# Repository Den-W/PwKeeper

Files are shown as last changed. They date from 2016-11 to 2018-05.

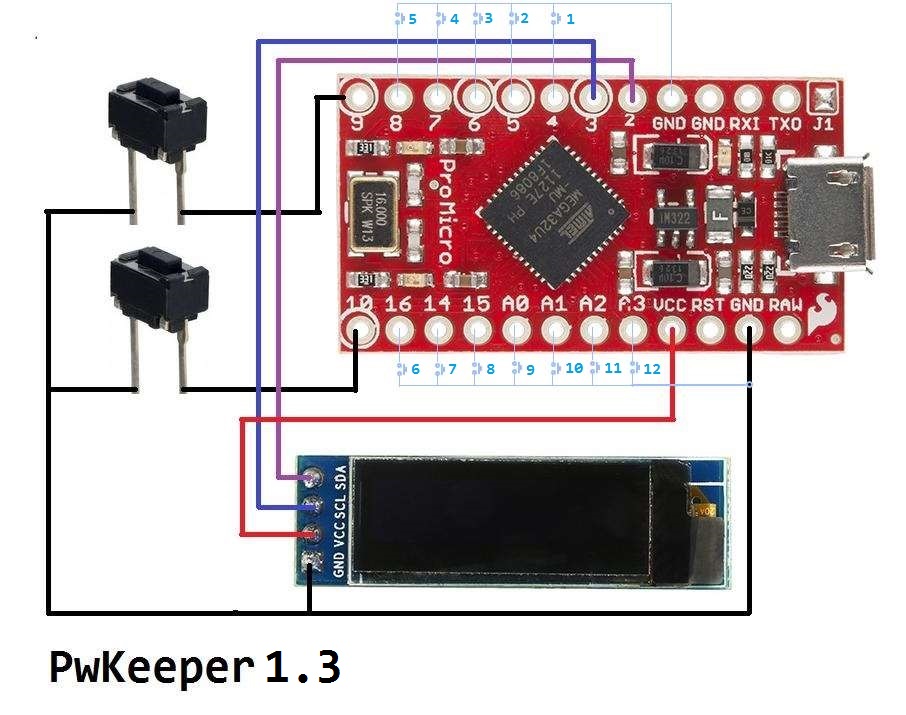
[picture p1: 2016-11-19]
PwKeeper-wiring.jpg

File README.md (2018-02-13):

*****************   PasswordKeeper v1.05   ***********************

This is a simple hand made device for storing your passwords.
Essentially, it emulates USB keyboard and should work with any device where USB keyboard may be connected.
It sends user-defined sequences of keypresses as if they were entered from keyboard.
To simplify password management in token Windows program PwKeeperPC.exe is included into the package.
Also, serial console added to device. It allows config device from *nix systems.

------------------------------------------------------------------
How to write HEX to board:

1) Download and install software from arduino.cc
2) Connect your board to PC and install all necessary drivers.
3) Open DeviceManager window. Open COM and LPT node. There you should see you board as virtual COM port.
4) On Arduino board connect RST pin to GND.
5) In COM and LPT node new COM port should appear on ~8 sec. And then it replaced by port, which you have seen already.
   If you do not see new ports to appear try to repeat step 4, but connect RST to GND 2 times with interval of 1 sec between tries.
6) Replace COM16 in command in CMD file with port, which appears temporarily.
   Check pathes to AVRDUDE.EXE and avrdude.conf in command.
   Correct it according to your system.
7) Connect RST pin to GND. Start CMD and remove RST to GND connection.
   Download to board should pass.

Essentialy, COM port that you see when board is in idle state - it is HID port. It is not the LOADER port. Board LOADER COM appears only on short period after reset.
-------------------------------------------------------------------   

Changes history:

v1.5 - 13.02.2018
        - Bugfix in login transmit procedure.

v1.4 - 24.11.2016
	- *nix-like TTY console added to PwKeeper
	- Commands description added to rtf.

v1.3 - 16.11.2016
	- Several bugfixes in PwKeeperPC.exe
	- Several bugfixes in PwKeeper.hex
 	- *.stl files added
	- Quick access buttons added to wiring diagram

v1.2 - 10.11.2016 
	- First public release

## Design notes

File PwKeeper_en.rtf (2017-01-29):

Password Keeper v 1.04.
Url: Instruction (http://www.instructables.com/id/PasswordKeeper-From-Aruino-Pro-Micro-or-Why-Keep-I/)

1. Menu structure
• Password
If main password is not set, then jump on Selection.
!!! If you forgot the main password – there is no way to restore it.
!!! You should clear all data in token – that will reset password to empty.
o Up, Down, Double Up, Double Down
Enter password data.
o Long Up => If password OK, then jump on Selection
o Long Down => Jump on Reset. – If you forgot password
• Select record
o Up, Down – Move up or down.
o Double Up, Long Up => Send data to USB.
o Double Down => Edit record
o Long Down => Device Menu
• Edit record
o Up, Down – Change current selection.
Disp – Displayed comment
Name – Login
Psw - Passwors
Del! - Delete entire record.
o Double Up, Long Up => Edit text field.
o Double Down, Long Down => Jump to Selection or Save
• Edit text field
o Up, Down – Move along the string.
o Double Up, Long Up => Edit symbol.
o Double Down, Long Down => Edit record.
• Edit symbol
o Up, Down – Change symbol.
o Double Up, Double Down => jump to Edit text field.
o Long Up – Add symbol.
o Long Down – Delete symbol.
• Device menu
o Up, Down – Change current selection.
o USB – Communicate with PwKeeperPc.
TTY – *NIX serial console
PSW – Set main password
CLR – Jump to Reset.
o Double Up, Long Up => select action.
o Double Down, Long Down => Exit.
If data were changed, jump to Save.
• Reset
o Double Up, Long Up – Clear all data in PwKeeper, including main password.
o Up, Down, Double Down, Long Down – Do not clear.
• Save
o Double Up, Long Up – Save changed data.
o Up, Down, Double Down, Long Down – Restore previous data.

2. Special symbols and macros

Key | Press | Release
KEY_LEFT_ALT | \a | \A
KEY_BACKSPACE | \b | \B
KEY_LEFT_CTRL | \c | \C
KEY_DELETE | \d | \D
KEY_ESC | \e | \E
KEY_RIGHT_SHIFT | \f | \F
KEY_RIGHT_ARROW | \g | \G
KEY_HOME | \h | \H
KEY_INSERT | \i | \I
KEY_CAPS_LOCK | \k | \K
KEY_LEFT_ARROW | \l | \L
KEY_END | \n | \N
KEY_PAGE_DOWN | \o | \O
KEY_PAGE_UP | \p | \P
KEY_RIGHT_ALT | \q | \Q
KEY_RETURN | \r | \R
KEY_LEFT_SHIFT | \s | \S
KEY_TAB | \t | \T
KEY_UP_ARROW | \u | \U
KEY_LEFT_GUI | \v | \V
KEY_DOWN_ARROW | \w | \W
KEY_RIGHT_GUI | \x | \X

Delay 300ms \z
Delay 1000ms \Z
Release all buttons \@
Sequence \[….]

For example, Ctrl-Alt-Del may be coded as \c\a\v\z or \[cavz]

System login and WORD start example:
Disp: Work-Comp V1: \[cavz
Login: V5:\[zv]word\r
Passw: Secret123\r

Site login example:
Disp: MyBank
Login: 45978726234\t
Passw: zzFFeerrr123\r

3. TTY - *NIX serial console

A serial console added in v1.04 firmware. It’s a courtesy for *nix community. This console allows editing of data inside PwKeeper by several VI-like commands. For console activation it is necessary manually select menu item “Device Menu”->”TTY”. After entering into TTY mode PwKeeper opens virtual COM port. Use any suitable terminal program for interaction with it. In TTY mode device echoes all incoming strings and shows all fields of current record.

Commands:
? - Show brief commands help.
U - Go to first record
D - Go to last record
u - Go one record up
d - Go one record down
W - Set main password. Main password sets by a combination of chars:
u – Upper button click
U – Upper button double click
d – Lower button click
D – Lower button double click
uuDDUd = 2 click up, 2 doubleclick down, 1 doubleclick up, 1 click down
!!! It is very dangerous command. You must enter password on following powerups!
A - Add new record
E - Erase current record entirely
C - Set Comment field of current record.
N - Set Name field of current record.
P - Set Password field of current record.
1-9 - Set V1 – V6 fields of current record.
Examples:
>WuuDd - Set main password: 2 single UP click, 1 double down, 1 single down.
>U - Go to first record in token
>CAOL-my - Set comment of current record to “AOL-my”
>3 - Remove field V3
>1\[cavz - Set field V1 to Ctrl-Alt-Del + delay(300)

4. Loading of HEX file and connecting with PwKeeperPc.
There is LOAD_HEX.CMD file for loading HEX into Arduino Pro Micro in the project on GITHUB (https://github.com/Den-W/PwKeeper).
1) Install Arduino IDE (http://arduino.ru/Arduino_environment) and check pathes to AVRDUDE.EXE and avrdude.conf in command below. Correct it according to your system.
!!! Important !!! If there are spaces in path on your system, do not forget frame all path with ““
2) Open DeviceManager window on COM and LPT node.
3) Plug in Arduino Pro Micro to PC USB or connect RST pin with GND 2 times with 1 sec interval.
4) In COM and LPT new COM port should apper. After ~8 it would change its number on another one, which you will see all the time, while device connected to PC.
Replace COM16 in the command with port, which you see first after reset\plug in.
Not the one you see all the time!
5) After editing CMD file repeat reset procedure or replug token to PC.
While “disappearing” COM port is still visible start LOAD_HEX.CMD.
Loading should pass. You will see 0\0 and blinking dot on the screen.

PwKeeperPc:
For connecting with PwKeeperPc you should go to DeviceMenu.
Do Lower Button Long Press. Select USB and do Double or long press on upper button.
You should see USB: 0\0 on the screen.
Then you may press Read\Write buttons on PwKeeperPC.
PwKeeperPc can see token only in this mode.

Unix\Serial console:
For connecting with token in command mode you should go to DeviceMenu.
Do Lower Button Long Press. Select TTY and do Double or long press on upper button.
You should see TTY: 0\0 on the screen.
Then start any suitable communication program on COM port.
In Arduino IDE you may use built-in console (Ctrl-Shift-M). With VI-like commands you may edit data in token.

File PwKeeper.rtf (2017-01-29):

Password Keeper v 1.04.
Описание: Ссылка1 (http://mysku.ru/blog/aliexpress/46651.html), Ссылка2 (http://radiokot.ru/circuit/digital/security/53/)

1. Структура меню устройства.

• Пароль
Если главный пароль не установлен, PwKeeper сразу переходит к Выбору
!!! Если вы забыли пароль – восстановить его нельзя, только стереть все данные в устройстве и сбросить пароль в пустой !!!
o Up, Down, Double Up, Double Down
Ввод символов пароля.
o Long Up => если пароль правильный переход к Выбору.
o Long Down => Переход на Сброс. – Если вы забыли пароль.
• Выбор записи
o Up, Down – движение по списку.
o Double Up, Long Up => Отправить пароль.
o Double Down => Редактирование записи
o Long Down => Меню настроек устройства
• Редактирование записи
o Up, Down – движение по меню.
Disp – Комментарий
Name – Login
Psw - Пароль
Del! - Удалить запись целиком.
o Double Up, Long Up => редактировать элемент.
o Double Down, Long Down => Выбор записи или Сохранение данных
• Редактировать элемент
o Up, Down – движение по строке.
o Double Up, Long Up => Редактировать символ
o Double Down, Long Down => Редактирование записи
• Редактировать символ
o Up, Down – Смена символа.
o Double Up, Double Down => сохранить символ и перейти в Редактировать Элемент
o Long Up – Добавить символ
o Long Down – Удалить символ
• Меню настроек
o Up, Down – движение по меню.
USB – режим взаимодействия с PwKeeperPc
TTY – Консоль управления
PSW –Установить главный пароль
CLR – Переход на Сброс.
o Double Up, Long Up => выбор пункта.
o Double Down, Long Down => Выxoд
Если данные были изменены – переход на сохранение
• Сброс
o Double Up, Long Up – Cтереть все данные в устройстве.
o Up, Down, Double Down, Long Down – отказаться от сброса
• Сохранение данных
o Double Up, Long Up – Записать новые данные.
o Up, Down, Double Down, Long Down – отказаться от записи

2. Спецсимволы и макросы для управления кнопками

Кнопка | Нажать | Отпустить
KEY_LEFT_ALT | \a | \A
KEY_BACKSPACE | \b | \B
KEY_LEFT_CTRL | \c | \C
KEY_DELETE | \d | \D
KEY_ESC | \e | \E
KEY_RIGHT_SHIFT | \f | \F
KEY_RIGHT_ARROW | \g | \G
KEY_HOME | \h | \H
KEY_INSERT | \i | \I
KEY_CAPS_LOCK | \k | \K
KEY_LEFT_ARROW | \l | \L
KEY_END | \n | \N
KEY_PAGE_DOWN | \o | \O
KEY_PAGE_UP | \p | \P
KEY_RIGHT_ALT | \q | \Q
KEY_RETURN | \r | \R
KEY_LEFT_SHIFT | \s | \S
KEY_TAB | \t | \T
KEY_UP_ARROW | \u | \U
KEY_LEFT_GUI | \v | \V
KEY_DOWN_ARROW | \w | \W
KEY_RIGHT_GUI | \x | \X

Задержка на 300мс \z
Задержка на 1000мс \Z
Отпустить все кнопки \@
Последовательность \[….]

Например, Ctrl-Alt-Del можно записать как \c\a\v\z или как \[cavz]

Пример настроек для входа в систему:
Имя: Комп-Работа V1: \[cavz
Login: Ivanov_PS\t V5:\[zv]word\r
Пароль: Secret123\r

Пример настроек для входа в банк:
Имя: Сбер-Дебет
Login: 45978726234\t
Пароль: zzFFeerrr123\r

3. TTY - *NIX консоль управления

В firmware v1.04 добавлена консоль управления, специально для работы с устройством из *nix ОС. Эта консоль позволяет редактировать данные в PwKeeper с помощью нескольких команд, похожих по синтаксису на VI команды.
Для запуска консоли надо выбрать кнопками пункт меню “Device Menu”->”TTY”. После старта открывается виртуальный COM порт. К нему можно подсоединиться любой подходящей программой эмуляции терминала. В режиме TTY устройство отправляет обратно все введенные строки и отображает все поля текущей записи.

Команды:
? - Краткий справочник команд.
U - Переход на первую запись
D - Переход на последнюю запись
u - Переход на одну запись вверх
d - Переход на одну запись вниз
W - Установить главный пароль. Пароль состоит из символов:
u – Однократное нажатие вверх
U – Двукратное нажатие вверх
d – Однократное нажатие вниз
D – Двукратное нажатие вниз
uuDDUd = 2 up, 2 double down, 1 double up, 1 down
!!! Это опасная команда. Этот пароль будет всегда требоваться при включении!
A - Добавить новую запись
E - Удалить текущую запись
C - Установить поле Comment.
N - Установить поле Name.
P - Установить поле Password.
1-6 - Установить поля V1 – V6.
Примеры:
>WuuDd - Установить главный пароль: 2 single up, 1 double down, 1 single down.
>U - Перейти к первой записи
>CAOL-my - Установить отображаемый коментарий в “AOL-my”
>3 - Удалить поле V3
>1\[cavz - Установить поле V1 в Ctrl-Alt-Del + задержка 300 мс

4. Загрузка и работа
Для загрузки HEX в Arduino Pro Micro в проекте на GITHUB (https://github.com/Den-W/PwKeeper) есть файл LOAD_HEX.CMD.
1) Установить Arduino IDE (http://arduino.ru/Arduino_environment) и проверить путь к AVRDUDE.EXE и avrdude.conf. Исправьте пути в CMD в соответствии с Вашей системой.
!!! Важно!!! Если путь содержит пробелы, не забудьте обрамить его кавычками “ !
2) Откройте окно DeviceManager. Откройте COM and LPT узел.
3) Подключите Arduino Pro Micro к USB или замкните RST пин на GND 2 раза с интервалом около 1 сек.
4) В устройствах COM and LPT появится новый COM порт. И через ~8 сек он поменяется на другой, который будет виден пока устройство подключено.
Замените COM16 в команде на порт, который появлялся первым, а не на тот, что виден всегда!
5) После того, как в CMD файл внесены изменения повторите процедуру сброса или подсоедините плату к компу заново. Пока виден “исчезающий” COM порт запустите LOAD_HEX.CMD.
Загрузка должна пройти. Вы увидите на экране 0\0 и мигающую точку – значит все работает.

PwKeeperPc:
Для соединения с PwKeeperPc вам нужно перейти в МенюНастроек.
Для этого при первом включении выполните долгое нажатие кнопки Вниз, выберите пункт USB и 2 раза или долго нажмите на верхнюю кнопку.
Появится надпись USB: 0\0.
После этого можно нажимать кнопки Чтение\Запись на PwKeeperPC. Программа PwKeeperPc видит токен только в этом режиме.

Unix\Serial console:
Для соединения в командном режиме вам нужно перейти в МенюНастроек.
Для этого при первом включении выполните долгое нажатие кнопки Вниз, выберите пункт TTY и 2 раза или долго нажмите на верхнюю кнопку.
Появится надпись TTY: 0\0.
Далее запустите какую-либо программу терминала. В Arduino IDE можно использовать встроенную консоль (Ctrl-Shift-M). Используя VI-подобные команды из параграфа 3 можно редактировать данные в токене.

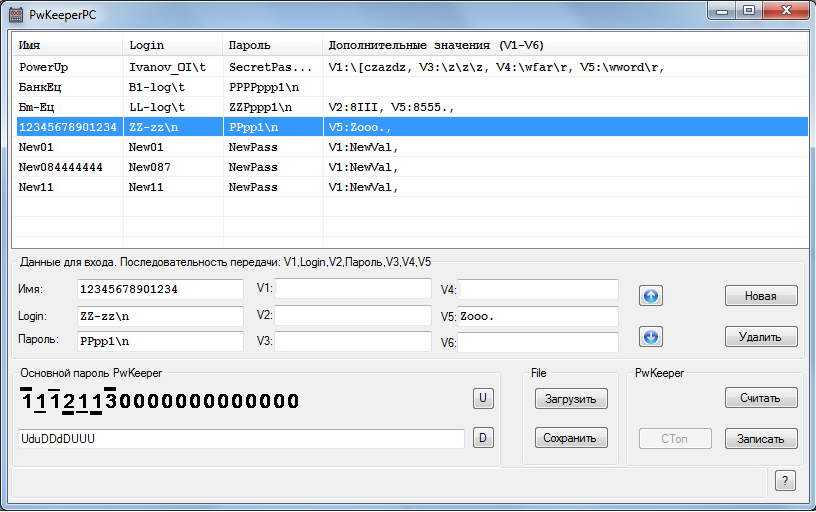
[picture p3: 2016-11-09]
PwKeeperPC.png

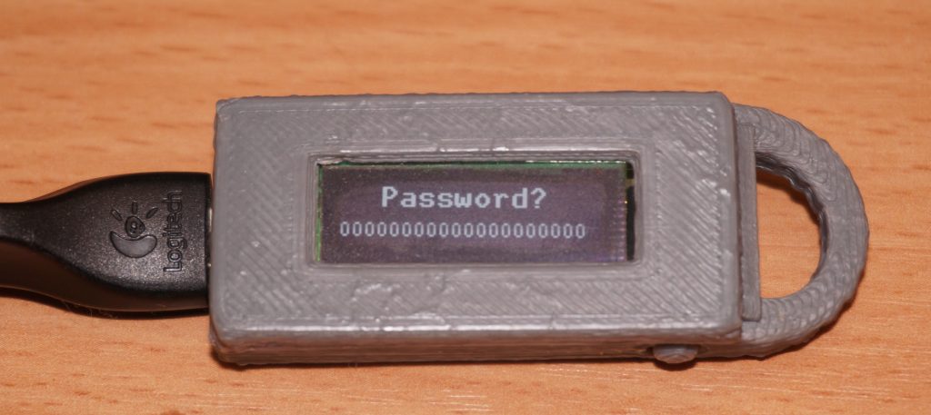
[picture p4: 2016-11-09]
PwKeeper-work.jpg

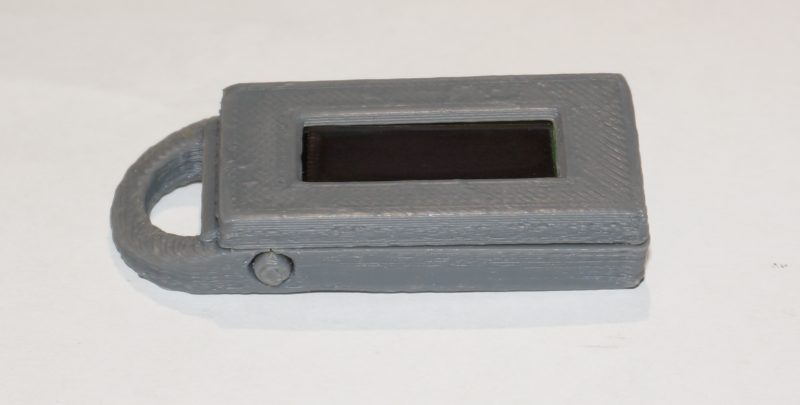
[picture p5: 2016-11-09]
PwKeeper-rdy.jpg

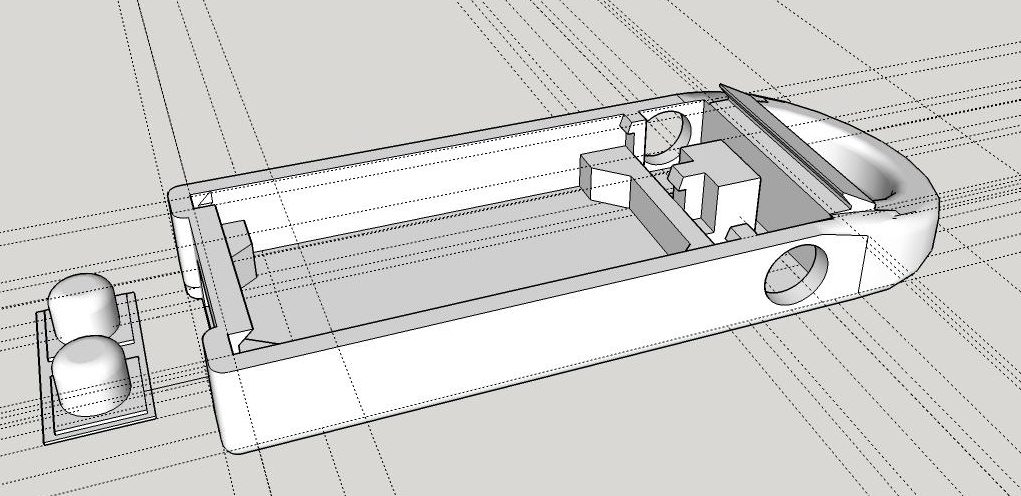
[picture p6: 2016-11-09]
PwKeeper_base_r.jpg

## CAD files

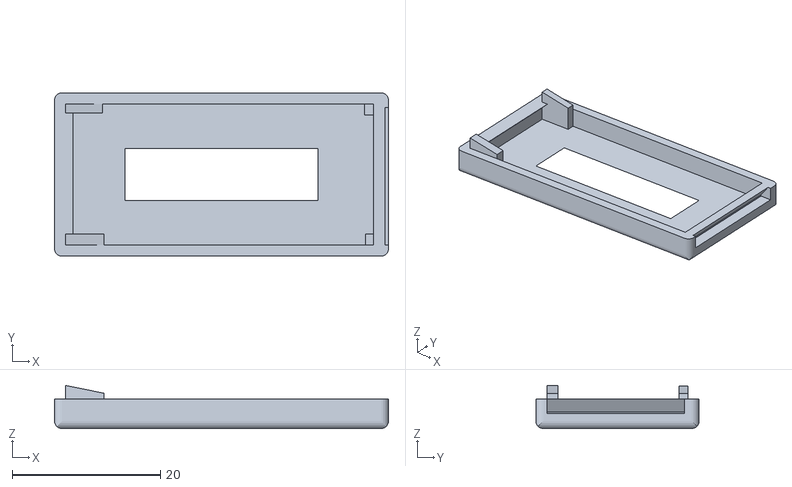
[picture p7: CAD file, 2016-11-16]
3D_Model/PwKeeper_lid_r.stl
45.0 x 22.0 x 5.80

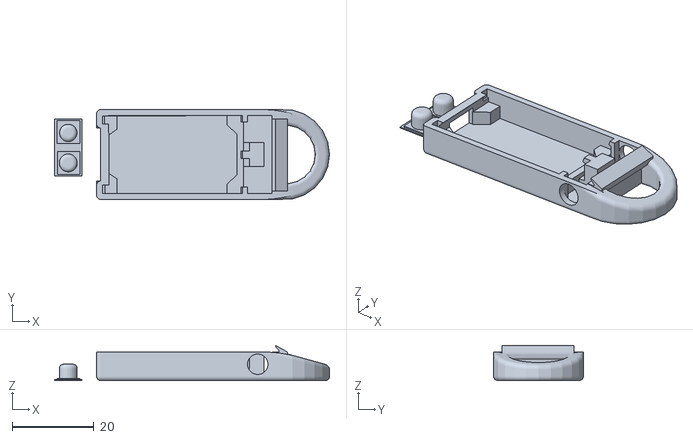
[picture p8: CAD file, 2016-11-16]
3D_Model/PwKeeper_base_r.stl
67.4 x 22.0 x 8.60

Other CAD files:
3D_Model/PwKeeper_base_r.skp
3D_Model/PwKeeper_lid_r.skp

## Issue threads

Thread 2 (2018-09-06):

Работа клавиатуры на уровне bios

me11ved, 2018-09-06:
Добрый день, есть зашифрованный диск с помощью программы truecrypt, при запуски пк нужно вводить пароль.

Вопросы:

- Может ли данное устройство вводить пароль на уровне bios?
- Если да, не будет ли конфликтов с usb клавиатурой подключенной к пк?

Спасибо

Den-W, 2018-09-06:
Добрый день,

Этот токен со стороны компа виден как USB клавиатура .
Если биос работает с USB клавиатурой - то и с токеном будет.
Конфликтов не будет - к компу можно подключить несколько клавиатур - и все они будут работать параллельно.
Токен - это просто еще одна клавиатура.

Есть подводные камушки:

1) Токен , по сути, посылает нажатия кнопок.
Пока идет латинский алфавит - все хорошо.
Но если вы захотите ввести русский текст - надо будет послать коды для переключения языка.
В описании есть команды нажатий Ctrl, Shift, Alt - итд (например одновременное нажатие Ctrl-Alt-Del).
Коды переключения на разных компах могут быть разные (Ctrl-Shift,Alt-Shift)

2) В проекте лежит полностью рабочий бинарник и исходник ino.
Но чтобы исходник после сборки правильно отображал русские буквы нужно подправить библиотеку u8g2. Может с новой версией u8g2 и так все работать будет. а может и нет.
Если на токене будут крокозябры - нужно смотреть процедуру трансляции русских букв в фонт.

Den-W, 2018-09-06:
Да
Enter это такая же кнопка, что и остальные.
Посмотрите в файле примеров - там все это есть.
типовой сценарий: CtrlAltDel-Имя-Tab-Пароль-Enter

Closed 2018-09-06.

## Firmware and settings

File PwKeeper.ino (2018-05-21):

#include <Arduino.h>
#include <stdio.h>
#include <EEPROM.h>
#include <U8glib.h>
#include <Keyboard.h>
#include "OneButton.h"
#include <avr/pgmspace.h>

#define  PIN_BTN_UP       A9      // Button UP
#define  PIN_BTN_DN       A10     // Button DOWN
#define  RXLED            17      // RX led pin

//                        0x01-0x0E - Fast key access    
#define  BTN_UP           0x20    // UP
#define  BTN_DOWN         0x21    // DOWN
#define  BTN_ENT          0x22    // Enter == DoubleUp
#define  BTN_ESC          0x23    // Esc == DoubleDown
#define  BTN_INS          0x24    // Ins == LongUp
#define  BTN_DEL          0x25    // Del = LongDown
#define  MAX_DATA         1000    // Max data size
#define  MAX_PASSWORD     20      // Max password length
#define  MAX_BUFFER       128     // Max IO size
#define  MAX_EDIT         64      // EditStr size. <= MAX_BUFFER

#define  VERSION       	  "1.5"   // Version string

typedef unsigned long DWORD;

/*
 START
 * RESET - LongPressDOWN
 * PASSWORD - Enter password   
   * SELECT - Up, Down
     * SendPassword - Enter, Ins
     * SelectRecord - Up, Down
     * ConfigMenu   - Del
       * M_CFG_USB
       * M_CFG_PASSW
       * M_CFG_RESET
     * EditRecord   - Esc
       * Select Tag - Up, Down
       * Return     - Esc
       * EditTag    - Enter
         * Select Char - Up, Down
         * Edit char   - Enter, Ins
         * Return      - Esc     
 */

class CGlobalData
{   
  public:
    typedef   void (*pFUNC)( void );    
    
    byte    _St;
    byte      mPassword[MAX_PASSWORD];// 0x20:Up, 0x10:Double, 0x0F:ClickN
    byte      mData[MAX_DATA];  // EEProm data. 00:Nothing, 01:ShowName, 02:SendName, 03:SendPassw, 04:SendCite
    byte    _Wr;                // Data between _St and _Wr stored in flash memory. _Wr == crc8 of block
        
    byte      mChanged;         // mData changed    
    byte      mIsPw;            // Password checked
    short     mRecOffset;       // Record ofset in mData
    byte      mKey;             // Pressed key
    byte      mKeyUpLp;         // In key UP LongPress
    byte      mKeyDnLp;         // In key Dn LongPress
    byte      mPosMenu;         // current selected item
    byte      mPosEdit;         // Position in mEditStr
    byte      mPass;            // loop() pass counter
    byte      mWaitKey;         // Wait key before call to proc
    byte      mRecCur;          // Current Record No
    byte      mRecAll;          // Total Record count
    short     mUsbRx;           // Usb RXed data
    short     mUsbTx;           // Usb TXed data
    long      mIdleTo;
    char      mEditStr[MAX_BUFFER];// Edit buffer for value correction    
    byte    _En;
    
    OneButton mBtUp, mBtDn;     // Button handlers
    pFUNC     mpfRun, mpfRunPrev;
    pFUNC     mpfDisp, mpfDispPrev;

    CGlobalData() : mpfRun(0), mpfRunPrev(0), mpfDisp(0), mpfDispPrev(0),
                    mBtUp( PIN_BTN_UP, true), mBtDn( PIN_BTN_DN, true)
    { memset( &_St, 0, &_En-&_St );      
    }

    void  SetFunc( pFUNC fRun, pFUNC fDisp ) 
          {   if( !fRun ) 
              {  mpfRun = mpfRunPrev; 
              } else 
              {  mpfRunPrev = mpfRun; 
                 mpfRun = fRun;                
              }
              if( !fDisp ) mpfDisp = mpfDispPrev; 
              else {  mpfDispPrev = mpfDisp; 
                      mpfDisp = fDisp; 
              }              
          }
    void  Start(void);
    void  Run(void);
    void  Draw(void); 
    void  FlashRd(void);
    void  FlashWr(void);
    void  SetRecCntr( void );
    void  DrawUsb( const char *Pfx );
    void  DrawYN( const __FlashStringHelper *Msg );
    void  DrawLabels( const __FlashStringHelper *UpStr, const __FlashStringHelper *DnStr );
    void  PrnPrm( int PosN, int X, const __FlashStringHelper *Name );
    void  SerTx( int TxSz, const void *Tx, char *Hdr=0 );
    int   GetFastButton( void );
    int   GetLine( void );
    int   DelCurRec( void );

    static void  fStart(void);  // Start point
    static void  fPassword(void); static void  fDispPassword(void);   // Enter&check main password
    static void  fReset(void);    static void  fDispReset(void);      // Reset all Yes/No?
    static void  fSelect(void);   static void  fDispSelect(void);     // Select record
    static void  fRecMenu(void);  static void  fDispRecMenu(void);    // Select Record tag
    static void  fRecTagPos(void);static void  fDispRecTagPos(void);  // Select position in tag
    static void  fRecTagEdt(void);static void  fDispRecTagEdt(void);  // Edit char in tag
    static void  fRecDel(void);   static void  fDispRecDel(void);     // Delete record Yes\No?
    static void  fRecSave(void);  static void  fDispRecSave(void);    // Save changes Yas\No?
    static void  fCfgMenu(void);  static void  fDispCfgMenu(void);    // Config menu
    static void  fCfgPwd(void);   static void  fDispCfgPwd(void);     // Get new password
    static void  fCfgPwd2(void);  static void  fDispCfgPwd2(void);    // Repeat new password & set
    static void  fUsbIo(void);    static void  fDispUsbIo(void);      // External control
    static void  fTty(void);      static void  fDispTty(void);        // External TTY console
        
    void  SetEditStr( void );
    int   PwdEnter( void );
    void  KbdSend( void );
    void  Defaults( void )
          { memset( &_St, 0, &_En-&_St );
            FlashWr();
          }    
};

static CGlobalData gD;
U8GLIB_SSD1306_128X32 u8g(U8G_I2C_OPT_DEV_0|U8G_I2C_OPT_NO_ACK|U8G_I2C_OPT_FAST);  // Fast I2C / TWI 
const byte PinNoFast[] = { 4,5,6,7,8,16,14,15,18,19,20,21,0 };

//-----------------------------------------------------------------------------

void setup(void) 
{ gD.Start();
}

void loop(void) 
{ gD.Run();
}

// Button handlers
void hBtUpSingle()  { gD.mKey = BTN_UP; }
void hBtUpDouble()  { gD.mKey = BTN_ENT; }
void hBtUpLongSt()  { gD.mKeyUpLp = 1; gD.mKey = BTN_INS; }
void hBtUpLongEnd() { gD.mKeyUpLp = 0; }
void hBtDnSingle()  { gD.mKey = BTN_DOWN; }
void hBtDnDouble()  { gD.mKey = BTN_ESC; }
void hBtDnLongSt()  { gD.mKeyDnLp = 1; gD.mKey = BTN_DEL; }
void hBtDnLongEnd() { gD.mKeyDnLp = 0; }

//-----------------------------------------------------------------------------

int   CGlobalData::GetFastButton( void )
{ int i, n;

  for( i=0; PinNoFast[i]; i++ )
   if( LOW == digitalRead( PinNoFast[i] ) ) break;   // read the input pin

  if( !PinNoFast[i] ) return 0;
  
  for( n=0; n<10; n++ )
  { delay( 50 );
    if( LOW != digitalRead( PinNoFast[i] ) ) break;   // read the input pin
  }
  
  if( n < 4 ) return 0;
  if( n < 8 ) return i+1;   
  
  return (i+1) | 0x10;   
}

//-----------------------------------------------------------------------------

void  CGlobalData::Start(void) 
{ FlashRd();  // Read data from eeprom
  mIdleTo = millis();
//  Serial.begin( 115200 );

  for( int i=0; PinNoFast[i]; i++ )
   pinMode( PinNoFast[i], INPUT_PULLUP ); // set pin to input  

  pinMode(RXLED, OUTPUT);  // Set RX LED as an output
  
  // flip screen, if required
  //u8g.setRot180();
  u8g.setColorIndex(1);

  mBtUp.setClickTicks( 300 );
  mBtDn.setClickTicks( 300 );
  mBtUp.attachClick( hBtUpSingle );
  mBtUp.attachDoubleClick( hBtUpDouble );
  mBtUp.attachLongPressStart( hBtUpLongSt );
  mBtUp.attachLongPressStop( hBtUpLongEnd );
  mBtDn.attachClick( hBtDnSingle );
  mBtDn.attachDoubleClick( hBtDnDouble );
  mBtDn.attachLongPressStart( hBtDnLongSt );
  mBtDn.attachLongPressStop( hBtDnLongEnd );
  
  mWaitKey = 0;
  SetFunc( fStart, 0 );
  SetRecCntr();
}

//-----------------------------------------------------------------------------

void  CGlobalData::Run(void) 
{ mPass++;
  mKey = 0;
  mBtUp.tick();
  mBtDn.tick();

  if( mKey ) mIdleTo = millis();
  if( millis() - mIdleTo > 600*1000L ) 
  { mWaitKey = 0;
    SetFunc( fStart, 0 );
  }

  while( mpfRun )
  { if( mWaitKey && !mKey ) 
    { if( mpfRun != fSelect ) break;
      mKey = GetFastButton();
      if( !mKey ) break;
    }
    mWaitKey = 1;
    mpfRun();
    break;
  }
  
  // picture loop
  u8g.firstPage();  
  do 
  { u8g.setFont( u8g_font_9x18B );
    if( mPass & 0x10 ) u8g.drawBox( 126, 30, 2, 2 ); // Flasher
    if( mpfDisp ) mpfDisp();
  } while( u8g.nextPage() );
}

//-----------------------------------------------------------------------------

void CGlobalData::fStart(void)
{ TXLED0;
  digitalWrite(RXLED, HIGH);
  gD.mPosEdit = 0;
  gD.mIdleTo = millis();
  memset( gD.mEditStr, 0, sizeof(gD.mEditStr) );

  for( int i=0; i < MAX_PASSWORD; i++ )
  { if( gD.mPassword[i] == 0 ) continue;
    gD.SetFunc( gD.fPassword, gD.fDispPassword );
    return;
  }
  gD.SetFunc( gD.fSelect, gD.fDispSelect ); // Password == NULL
}

//-----------------------------------------------------------------------------

void CGlobalData::fPassword(void)
{ int   i = gD.PwdEnter();

  if( !i ) return;
  if( i < 0 )
  { gD.SetFunc( gD.fReset, gD.fDispReset );
    return;
  }

  if( memcmp( gD.mPassword, gD.mEditStr, MAX_PASSWORD ) ) 
  { gD.mWaitKey = 0;
    gD.SetFunc( gD.fStart, 0 ); // Passw bad, restart
    return;
  }
  gD.SetFunc( gD.fSelect, gD.fDispSelect ); // Password Ok
}

void CGlobalData::fDispPassword(void)
{ int   i, n, x, y;
  char  Tb[MAX_PASSWORD+2];

  u8g.drawStr( 20, 13, F("Password?") );
  u8g.setFont(u8g_font_6x12r);
  u8g.drawStr( 110, 7, F(VERSION) ); 
    
  for( i=0; i<MAX_PASSWORD; i++ )
  { n = gD.mEditStr[i];        
    Tb[i] = '0' | (n & 0x0F);
    if( n )
    { x = i*6+1;
      y = n & 0x20 ? 19:29;
      if( n & 0x10 ) u8g.drawBox( x, y+1, 3, 2 );
      else u8g.drawLine( x, y, x+3, y );
    }
  }
  Tb[MAX_PASSWORD] = 0;
  u8g.drawStr( 0, 28, Tb );
}

//-----------------------------------------------------------------------------

void CGlobalData::fReset(void)
{  switch( gD.mKey )
  {  case BTN_ENT:
     case BTN_INS:
        gD.Defaults();
        gD.SetFunc( gD.fStart, 0 );
        break;
     case BTN_DOWN:
     case BTN_ESC:
     case BTN_DEL:
        gD.SetFunc( 0, 0 );
  }
}

void CGlobalData::fDispReset(void)
{ gD.DrawYN( F("Clear all?") );  
}

//-----------------------------------------------------------------------------

void CGlobalData::fSelect(void)
{ int   i, n;
  switch( gD.mKey )
  {  case BTN_UP:
        for( i = gD.mRecOffset-1; i >= 0; i-- )
        { if( gD.mData[i] != 0x01 ) continue;
          gD.mRecOffset = i;
          gD.SetRecCntr();
          break;
        }
        break;
     case BTN_DOWN:
        if( !gD.mData[gD.mRecOffset] ) break; // End of record
        for( i = gD.mRecOffset+1; i < sizeof(gD.mData); i++ )
        { if( gD.mData[i] && gD.mData[i] != 0x01 ) continue;
          gD.mRecOffset = i;
          gD.SetRecCntr();
          break;
        }
        break;
     case BTN_ENT:
     case BTN_INS:
        gD.KbdSend(); // Send password
        break;    
     case BTN_ESC:
        gD.mChanged = 0;
        gD.mPosMenu = 0;            
        gD.SetFunc( gD.fRecMenu, gD.fDispRecMenu );
        break;
     case BTN_DEL:
        gD.mPosMenu = 0;
        memset( gD.mEditStr, 0, sizeof(gD.mEditStr) );
        gD.SetFunc( gD.fCfgMenu, gD.fDispCfgMenu );
        return;
        
     default: // mKey == RecordNo     
        for( i=n=gD.mRecOffset=0; gD.mRecOffset < sizeof(gD.mData); gD.mRecOffset++ )
        { switch( gD.mData[gD.mRecOffset] )
          { default: continue;
            case 0x01:
              i = gD.mRecOffset;
              if( ++n != (gD.mKey&0x0F) ) continue;
              if( gD.mKey & 0x10 ) gD.KbdSend();
              break;
            case 0x00:
              gD.mRecOffset = i;
              break;
          }
          gD.SetRecCntr();
          return;
        }
  }
}

void CGlobalData::fDispSelect(void)
{   int i = gD.mRecOffset, n = 0, x;
    char  Tb[16];

    memset( gD.mEditStr, 0, sizeof(gD.mEditStr) );
    if( gD.mData[i] ) 
    { for( i++; i<sizeof(gD.mData); i++ )
      { x = gD.mData[i] & 0x0FF;        
        if( x <= 0x01 ) break;
        if( x < 0x0A ) n = MAX_EDIT+1;
        if( n < MAX_EDIT )
          gD.mEditStr[n++] = x;
      }
      if( x ) u8g.drawBox( 121, 30, 4, 2 );
    }
    gD.mEditStr[32] = 0;
    u8g.drawStr( 0, 19, gD.mEditStr );
    if( gD.mRecOffset ) u8g.drawBox( 121, 0, 4, 2 );
    u8g.setFont(u8g_font_6x12r);
    sprintf( Tb, "%d/%d", gD.mRecCur, gD.mRecAll );
    u8g.drawStr( 0, 30, Tb ); 
}

//-----------------------------------------------------------------------------

void CGlobalData::fRecMenu(void)
{ switch( gD.mKey )
  {  case BTN_UP:
        if( ++gD.mPosMenu > 3 ) gD.mPosMenu = 0;
        gD.SetEditStr();
        break;
     case BTN_DOWN:
        if( --gD.mPosMenu > 3 ) gD.mPosMenu = 3;
        gD.SetEditStr();
        break;
     case BTN_INS:
     case BTN_ENT:
        if( gD.mPosMenu == 3 ) 
        { gD.SetFunc( gD.fRecDel, gD.fDispRecDel ); 
          break;
        }        
        gD.mPosEdit = 0;
        gD.SetFunc( gD.fRecTagPos, gD.fDispRecTagPos );
        break;
     case BTN_DEL:
     case BTN_ESC:
        if( !gD.mChanged ) gD.SetFunc( gD.fSelect, gD.fDispSelect );
        else gD.SetFunc( gD.fRecSave, gD.fDispRecSave );
        break;
  }
}

void CGlobalData::fDispRecMenu(void)
{   int i = gD.mPosEdit > 13  ? gD.mPosEdit-13:0;
    u8g.drawStr( 1, 13, gD.mEditStr+i );

    u8g.setFont(u8g_font_6x12r);
    gD.PrnPrm( 0,  0, F("Show") );
    gD.PrnPrm( 1, 32, F("Name") );
    gD.PrnPrm( 2, 64, F("Pass") );
    gD.PrnPrm( 3, 96, F("DEL!") );
}

//-----------------------------------------------------------------------------

void CGlobalData::fRecTagPos(void)
{ int   i, n;
  byte  b;

  switch( gD.mKey )
  {  case BTN_UP:
        if( gD.mPosEdit >= MAX_EDIT-1 ) break;
        if( gD.mEditStr[gD.mPosEdit] ) gD.mPosEdit++;
        else gD.mEditStr[gD.mPosEdit+1] = 0;
        break;
     case BTN_DOWN:
        if( --gD.mPosEdit > MAX_EDIT ) gD.mPosEdit = strlen(gD.mEditStr);
        break;
     case BTN_INS:
     case BTN_ENT:
        gD.SetFunc( gD.fRecTagEdt, gD.fDispRecTagEdt );
        break;
     case BTN_ESC:      
        gD.mPosEdit = 0;
        gD.SetFunc( gD.fRecMenu, gD.fDispRecMenu );        

        i = gD.mRecOffset;
        for( ; i < sizeof(gD.mData); i++ )
        { b = gD.mData[i];
          if( !b ) break;
          if( b != gD.mPosMenu+1 ) 
          { if( b == 0x01 ) break;
            continue;
          }          
          for( n = i+1; n < sizeof(gD.mData); n++ ) 
          { b = gD.mData[n];
            if( b <= 0x01 ) break;
          }
          if( n < sizeof(gD.mData) )
            memcpy( gD.mData+i, gD.mData+n, sizeof(gD.mData)-n );
          break;
        }
        n = strlen( gD.mEditStr )+1;
        if( i+n > sizeof(gD.mData) ) n = sizeof(gD.mData) - i;
        if( n > 0 ) memmove( gD.mData+i+n, gD.mData+i, sizeof(gD.mData)-(i+n) );
        gD.mData[i++] = gD.mPosMenu+1;
        memcpy( gD.mData+i, gD.mEditStr, n-1 );
        break;
     case BTN_DEL:
        gD.mPosEdit = 0;
        gD.SetFunc( 0, 0 );
        break;
  }
}

void CGlobalData::fDispRecTagPos(void)
{ int i = gD.mPosEdit > 13 ? 13:gD.mPosEdit;
  u8g.drawFrame( i*9, 0, 11, 16 );
  gD.fDispRecMenu();
}

//-----------------------------------------------------------------------------

void CGlobalData::fRecTagEdt(void)
{ byte  c;
  int   i, n;

  switch( gD.mKey )
  {  case BTN_UP:
        c = gD.mEditStr[gD.mPosEdit] + 1;
        if( c < ' ' ) c = ' ';
        else if( c > 0xFF ) c = ' ';
             else if( c == 0x7F ) c = 0xC0;
        gD.mEditStr[gD.mPosEdit] = c;
        gD.mChanged = 1;
        break;
     case BTN_DOWN:
        c = gD.mEditStr[gD.mPosEdit] - 1;
        if( c < ' ' ) c = 0xFF;
        else if( c == 0xBF ) c = 0x7E;            
        gD.mEditStr[gD.mPosEdit] = c;
        gD.mChanged = 1;
        break;
     case BTN_INS:
        if( gD.mPosEdit >= MAX_EDIT-1 ) break;
        i = strlen( gD.mEditStr );
        if( i >= MAX_EDIT-1 ) i = MAX_EDIT-1;
        i -= gD.mPosEdit;
        if( i > 0 ) memmove( gD.mEditStr+gD.mPosEdit+1, gD.mEditStr+gD.mPosEdit, i );
        gD.mEditStr[gD.mPosEdit] = 'A';
        gD.mChanged = 1;
        break;
     case BTN_DEL:
        strcpy( gD.mEditStr+gD.mPosEdit, gD.mEditStr+gD.mPosEdit+1 );
        gD.mChanged = 1;
        break;
     case BTN_ENT:
     case BTN_ESC:      
        gD.SetFunc( gD.fRecTagPos, gD.fDispRecTagPos );
        break;
  }
}

void CGlobalData::fDispRecTagEdt(void)
{   if( gD.mPass & 0x10 ) 
    { int i = gD.mPosEdit > 13 ? 13:gD.mPosEdit;
      u8g.drawFrame( i*9, 0, 11, 16 );
    }
    gD.fDispRecMenu();
}

//-----------------------------------------------------------------------------

void CGlobalData::fRecSave(void)
{ switch( gD.mKey )
  {  case BTN_UP:
        return;
     case BTN_ENT:
     case BTN_INS:
        gD.FlashWr();
        break;
     case BTN_DOWN:
     case BTN_ESC:
     case BTN_DEL:
        gD.mChanged = 0;
        gD.FlashRd();
        break;
  }
  gD.SetRecCntr();
  gD.SetFunc( gD.fSelect, gD.fDispSelect );
}

void CGlobalData::fDispRecSave(void)
{   gD.DrawYN( F("Save changes?") );      
}

//-----------------------------------------------------------------------------

void CGlobalData::fRecDel(void)
{ switch( gD.mKey )
  {  case BTN_ENT:
     case BTN_INS:
        if( !gD.DelCurRec() ) break;        
     case BTN_DOWN:
     case BTN_ESC:
     case BTN_DEL:      
        gD.SetFunc( gD.fRecMenu, gD.fDispRecMenu );
        break;
  }
}

void CGlobalData::fDispRecDel(void)
{ u8g.drawStr( 0, 20, gD.mEditStr );
  gD.DrawYN( F("Delete record?") );  
}

int  CGlobalData::DelCurRec(void)
{ int i, n;

  if( !gD.mData[gD.mRecOffset] ) return 0;
  for( i = gD.mRecOffset+1; gD.mData[i]>0x01 && i<sizeof(gD.mData); i++ );
  n = sizeof(gD.mData) - i;
  if( n <= 0 ) return 0;
  memcpy( gD.mData+gD.mRecOffset, gD.mData+i, n );
  memset( gD.mData+gD.mRecOffset+n, 0, sizeof(gD.mData)-(gD.mRecOffset+n) );
  gD.mChanged = 1;
  return 1;
}

//-----------------------------------------------------------------------------

void CGlobalData::fCfgMenu(void)
{ switch( gD.mKey )
  {  case BTN_UP:
        if( ++gD.mPosMenu > 3 ) gD.mPosMenu = 0;
        break;
     case BTN_DOWN:
        if( --gD.mPosMenu > 3 ) gD.mPosMenu = 3;
        break;
     case BTN_INS:
     case BTN_ENT:
        gD.mPosEdit = 0;
        switch( gD.mPosMenu )
        { case 0: // Enter USB exchange mode
            gD.mIsPw = 0;
            gD.mWaitKey = 0;
            gD.mUsbRx = gD.mUsbTx = 0;
            gD.SetFunc( gD.fUsbIo, gD.fDispUsbIo );
            break;
            
          case 1: // Enter TTY exchange mode
            gD.mWaitKey = 0;
            gD.mUsbRx = gD.mUsbTx = 0;
            gD.SetFunc( gD.fTty, gD.fDispTty );
            break;
            
          case 2:
            memset( gD.mEditStr, 0, sizeof(gD.mEditStr) );
            gD.SetFunc( gD.fCfgPwd, gD.fDispCfgPwd ); 
            break;
            
          case 3: 
            gD.SetFunc( gD.fReset, gD.fDispReset ); 
            break;
        }
        break;
     case BTN_DEL:
     case BTN_ESC:        
        if( !gD.mChanged ) gD.SetFunc( gD.fSelect, gD.fDispSelect );
        else gD.SetFunc( gD.fRecSave, gD.fDispRecSave );
        break;
  }
}

void CGlobalData::fDispCfgMenu(void)
{   u8g.drawStr( 1, 14, gD.mEditStr );
    u8g.setFont(u8g_font_6x12r);
    gD.PrnPrm( 0,  0, F("USB") );
    gD.PrnPrm( 1, 32, F("TTY") );
    gD.PrnPrm( 2, 64, F("Pass") );
    gD.PrnPrm( 3, 96, F("CLR!") );
}

//-----------------------------------------------------------------------------

void CGlobalData::fCfgPwd(void)
{ int i = gD.PwdEnter();
  if( i < 0 ) 
  { gD.SetFunc( gD.fCfgMenu, gD.fDispCfgMenu ); 
    return;
  }
  if( !i ) return;
  gD.mPosEdit = 0;
  memcpy( gD.mEditStr+32, gD.mEditStr, MAX_PASSWORD );
  memset( gD.mEditStr, 0, MAX_PASSWORD );
  gD.SetFunc( gD.fCfgPwd2, gD.fDispCfgPwd2 ); 
}

void CGlobalData::fDispCfgPwd(void)
{   gD.fDispPassword();
    u8g.setFont(u8g_font_6x12r);
    u8g.drawStr( 0, 7, F("New") );   
}

//-----------------------------------------------------------------------------

void CGlobalData::fCfgPwd2(void)
{ int i = gD.PwdEnter();
  if( i < 0 ) 
  { gD.SetFunc( gD.fCfgMenu, gD.fDispCfgMenu ); 
    return;
  }
  if( !i ) return;
  
  if( memcmp( gD.mEditStr+32, gD.mEditStr, MAX_PASSWORD ) ) 
  { gD.SetFunc( gD.fCfgMenu, gD.fDispCfgMenu ); 
    return;
  }
  gD.mChanged = 1;
  memcpy( gD.mPassword, gD.mEditStr, MAX_PASSWORD );
  gD.SetFunc( gD.fRecSave, gD.fDispRecSave );   
}

void CGlobalData::fDispCfgPwd2(void)
{   gD.fDispPassword();
    u8g.setFont(u8g_font_6x12r);
    u8g.drawStr( 0, 7, F("Rpt") );   
}
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
